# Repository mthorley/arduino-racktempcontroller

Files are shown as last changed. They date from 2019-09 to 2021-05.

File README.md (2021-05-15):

# Arduino Rack Temperature Controller

To temperature control and monitor a small (12U) network rack system using PWM fans and thermometers managed using an Arduino Mega with a custom designed shield:

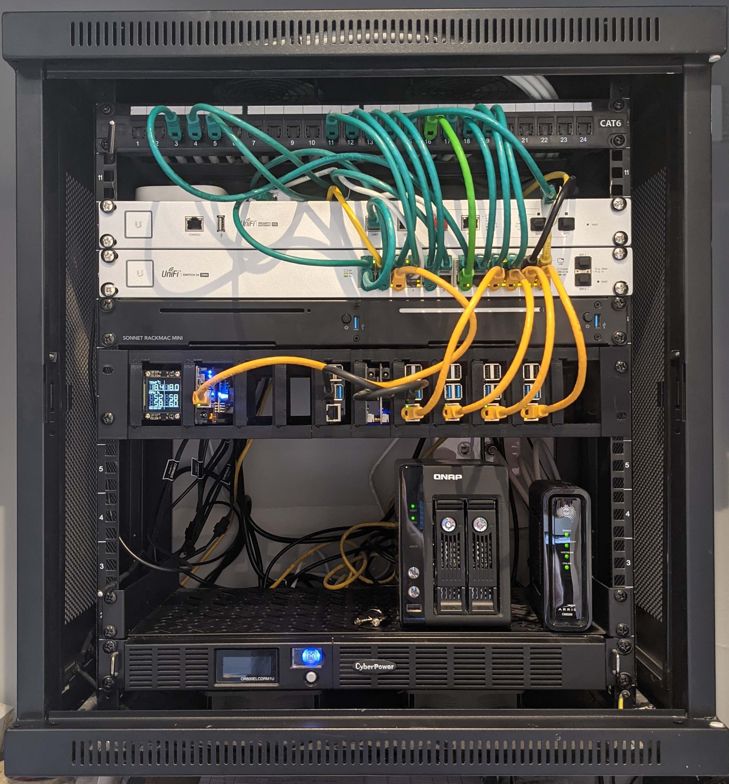
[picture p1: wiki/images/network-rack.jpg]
Image of Network Rack kit


Above rack has:
- 4 fans mounted (2 top and 2 base) in the rack
- 2 temperature sensors one at the top and base
- [Modular 3d printed model](https://github.com/mthorley/2u-rack-3dprint-model) 2U rack housing Arduino temperature controller and OLED shown far left

# Features and Specification
* Uses [Freetronics EtherMega](https://www.freetronics.com.au/collections/arduino/products/ethermega-arduino-mega-2560-compatible-with-onboard-ethernet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) Arduino board although likely any Mega board can reuse the shield
* Shield outline derived from Jonathan Oxer's [ProtoShieldMega](https://github.com/freetronics/ProtoShieldMega)
* Power over Ethernet 802.3af support using [Freetronics PoE module](https://www.freetronics.com.au/products/power-over-ethernet-regulator-8023af) to power the board (and reset it), thermometers, fans and display to simplify power and wire management
* Measures temperatures using [DS18B20](https://makeradvisor.com/tools/ds18b20-digital-temperature-sensor/) housed in metal cable assembly with an accuracy of +/- 0.5&deg;C
* Uses [Freetronics OLED](https://www.freetronics.com.au/pages/oled128-quickstart-guide) via SPI to display the temperature and fan states of the rack
* Works with PWM fans of either 5 or 12V and supports configurable frequency (default 25kHz)
* Uses an [passive infrared sensor](https://www.keyestudio.com/2016-new-keyestudio-pir-motion-sensor-for-arduino-p0488-p0488.html) to prevent burn in for OLED display, only enabling the display on a PIR trigger
* Monitors and displays fan tachometer output to verify RPM is within expected range and fan has not stalled
* Publishes all fan, temperature, error states and logs to an MQTT endpoint and topics for analysis and visualisation
* Software must support any number of temperature devices and fans to enable testing and reuse

# Initial Design
Initial design was based on a separate (non-shield) board using a [MAX31790](https://www.maximintegrated.com/en/products/sensors/MAX31790.html) for fan PWM control and tach measurement integrated with an Arduino Uno using I<sup>2</sup>C. However due to Uno memory limitations of <32k, I upgraded to the Mega with 256k. Code is however included under [MAX31790FanControl.cpp](src/MAX31790FanControl.cpp).

Using a Mega also enabled the PWM control and tach measurement to be done by the Mega pinout and all in software simplifying the overall hardware solution.

# Shield Design
The shield design outline is based on [ProtoShieldMega](https://github.com/freetronics/ProtoShieldMega). The top side of the PCB layout is illustrated. The schematic and PCB design files are under [Eagle](/Eagle). EAGLE PCB design software is available from https://www.autodesk.com/products/eagle/free-download and is free for non-commercial use.

## Pin Mapping
| Pin | Mapping |
|-----|---|
|2, 4, 7| OLED DC, Reset, CS |
|8 | Onewire DS for thermos |
| 11, 12, 5, 3 | Fan PWM 1-4 |
| 18, 19, 20, 21 | Fan Tach 1-4 for RPM interrupts |
| 6 | IR sensor |

## Schematic
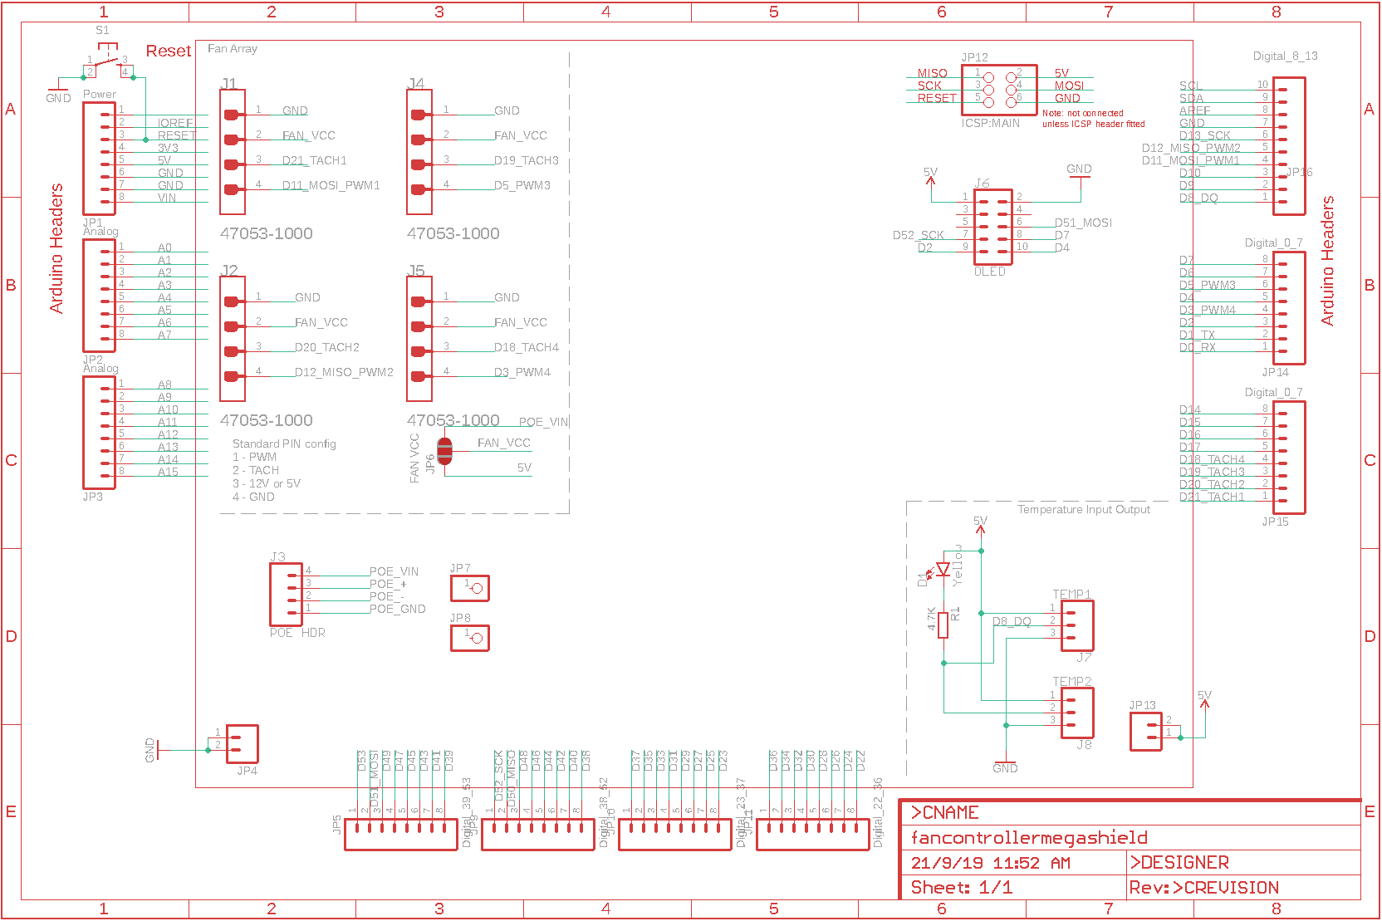
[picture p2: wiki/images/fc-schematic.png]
Shield schematic


## PCB
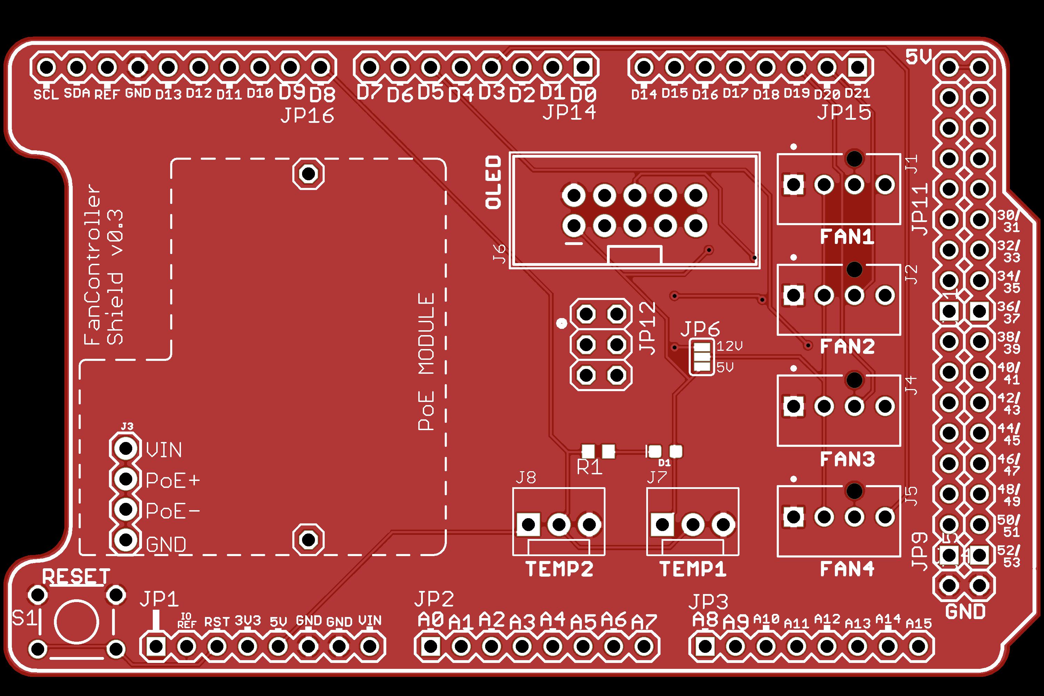
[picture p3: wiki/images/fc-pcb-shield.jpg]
Rack Temp Controller PCB


## Manufacture
I used [DirtyPCBs](https://dirtypcbs.com/store/pcbs) to manufacture the boards. They also support [design rules checking and CAM Gerber export](https://dirtypcbs.com/store/pcbs/about#cam) for EAGLE, which ensures the PCB layout conforms to their manufacture processes and the Gerber files produced will pass.

I then soldered (or used solder paste for surface mount) the parts in place. For the surface mount work, I used a heat gun and roughly followed the [heat profile](http://www.chemtools.com.au/download/technical-and-safety-data-sheets/solders-pastes-and-fluxes/SAC305CR318%20SAC305%20Solder%20Paste/SAC305CR318%20TDS.pdf) by modifying the gun temperature manually. [YouTube videos](https://www.youtube.com/watch?v=W0BhGieg4II) explain how to do this. 

## Shield Mounted
The shield mounted with the EtherMega.

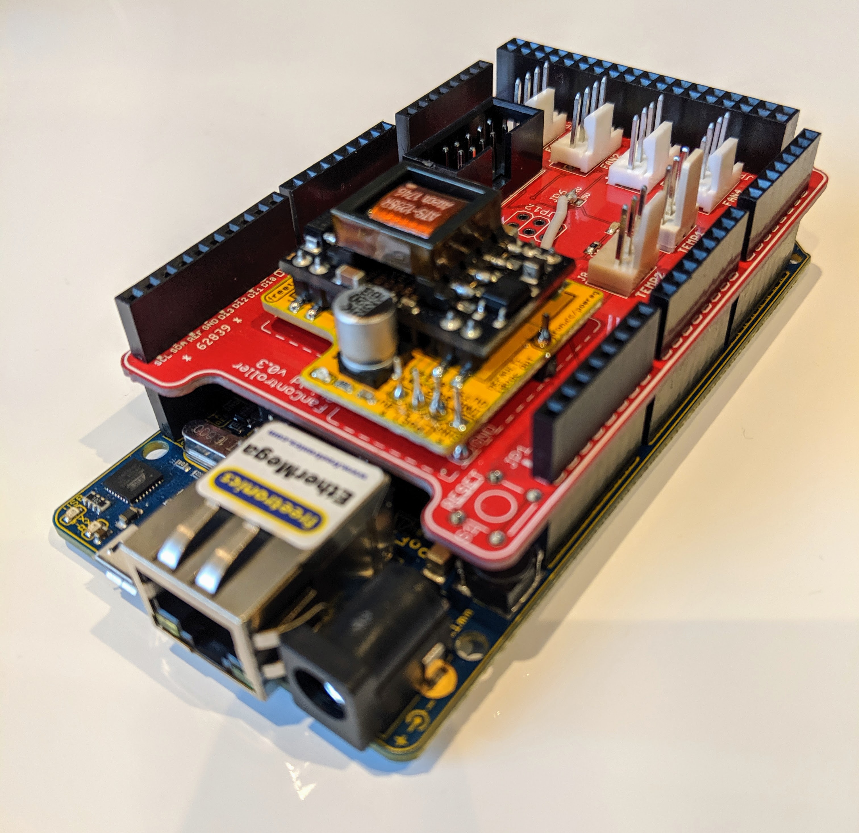
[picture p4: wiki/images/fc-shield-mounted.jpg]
Shield mounted


Minor error on the power circuit which required a track cut and wire from VIN to Fan power. This has been corrected on the Eagle files.

# Display
OLED display to render fan and temperature states showing the fan temperatures in the top row, and the fan RPMs as a percentage of maximum RPM in the lower rows. The fan RPM % does not always accurately map to the input PWM duty cycle - the [fans](https://noctua.at/en/nf-s12b-redux-1200-pwm/specification) I am using have a +/- 10% variance on RPM. The display also supports 90 degree rotation to support rack mounting.

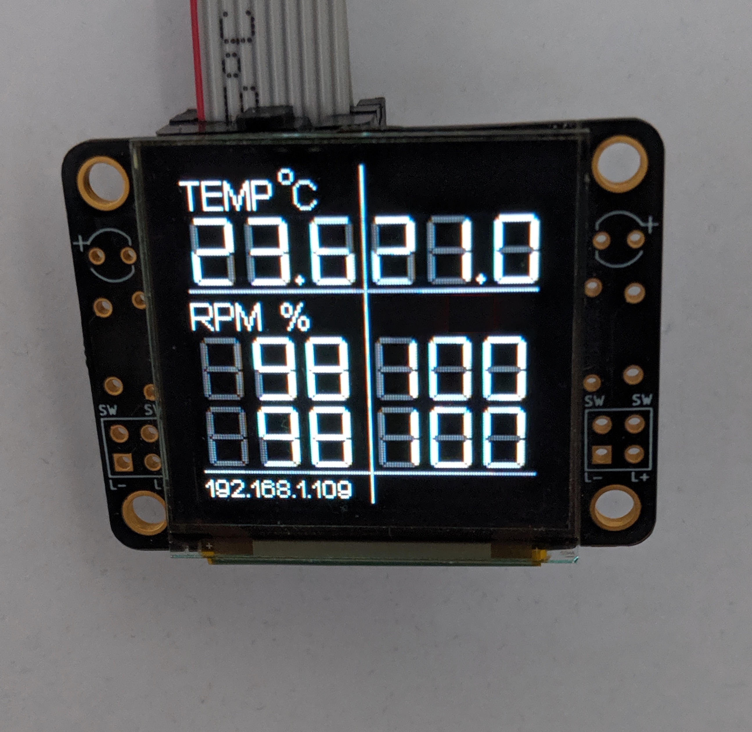
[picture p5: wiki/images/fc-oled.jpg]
OLED display


## Font Generation for OLED
Generated new fonts using [GLDCFontCreator](https://github.com/freetronics/FTOLED/wiki/Displaying-Text#defining-new-fonts).

## MQTT Dashboard
I used the mobile app [IoT MQTT Panel](https://play.google.com/store/apps/details?id=snr.lab.iotmqttpanel.prod&hl=en) to render the MQTT topics which supports configurable panels per topic and different rendering options:

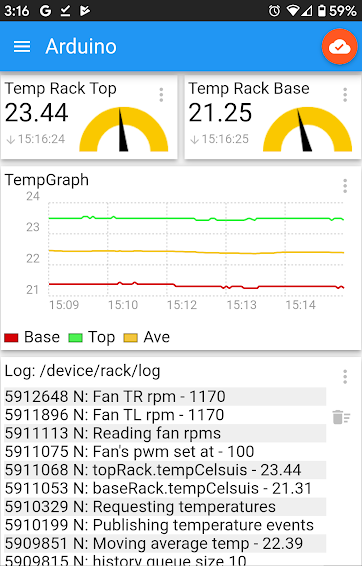
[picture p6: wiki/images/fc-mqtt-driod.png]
MQTT dashboard


# Code 
Development done using [PlatformIO](https://platformio.org/) which supports multiple boards and library management.  

## Explanation
The main routine loop executes the [RackTempController](src/RackTempController.cpp) process method below which reads the temperature sensors, adjusts the fan speed based on the temperatures, reads and verifies the fan speed RPM is as requested by the PWM dutycycle within a tolerance and analyses temperature trends using a moving average.

```c++ 
void RackTempController::process(RackState_t& rs) {
    
    // read temperatures
    readTempStates(rs.thermos);

    // adjust fan speeds based on temps
    adjustFanSpeeds(rs);
    
    // read fan tach/rpms - delay of 750ms per fan
    readFanSpeeds(rs.fans);

    // verify fan PWMs matches RPMs
    verifyFanStates(rs.fans);

    // analyse trends
    analyseTrends(rs);
};
```
Thermos and fan configuration is created via [RackTempController::build()](src/RackTempController.cpp#L219) which enables any number of thermos or fans to be used. The OLED display class however, is fixed to the specification above.

## Dependent Libraries

All libraries were loaded and managed used PlatformIO's library management. 

| Library | Purpose |
|---|---|
| DallasTemperature | Measures temperature of DS18* devices using OneWire |
| FTOLED  | Graphics library to drive OLED |
| SD | Dependency for FTOLED - not used |
| Ethernet | Ethernet, DHCP support |
| ArduinoMqttClient | MQTT client |
| TimerOne | PWM control for Timer1 |
| TimerThree | PWM control for Timer3 |
| ArduinoLog | Logging framework |
| ArduinoSTL | STL library used for map, vector etc |

## Rack Mount

Further details on the rack mount design: [3D printed model](https://github.com/mthorley/2u-rack-3dprint-model).

# TODO
- Update this README!
- Create a config endpoint - possibly via MQTT subscribe to enable changes to MQTT params, temp threshold etc. 
- Improve MQTT events
- Watchdog via AWS lambda which reboots via PoE
- Look at FreeRTOS or [Helios](https://github.com/MannyPeterson/HeliOS) and work out if its worth it
- Make it cheaper

# Credits
First and foremost to [Jonathan Oxer](https://www.patreon.com/superhouse).

Secondly all the excellent library contributors used in the project.

# License
Hardware design licensed under the TAPR Open Hardware License (www.tapr.org/OHL) and GNU. The [license](Eagle/license) folder within this repository also contains a copy of this license in plain text format.

Software licensed under GPLv3 - see [license.md](license.md) file for details.

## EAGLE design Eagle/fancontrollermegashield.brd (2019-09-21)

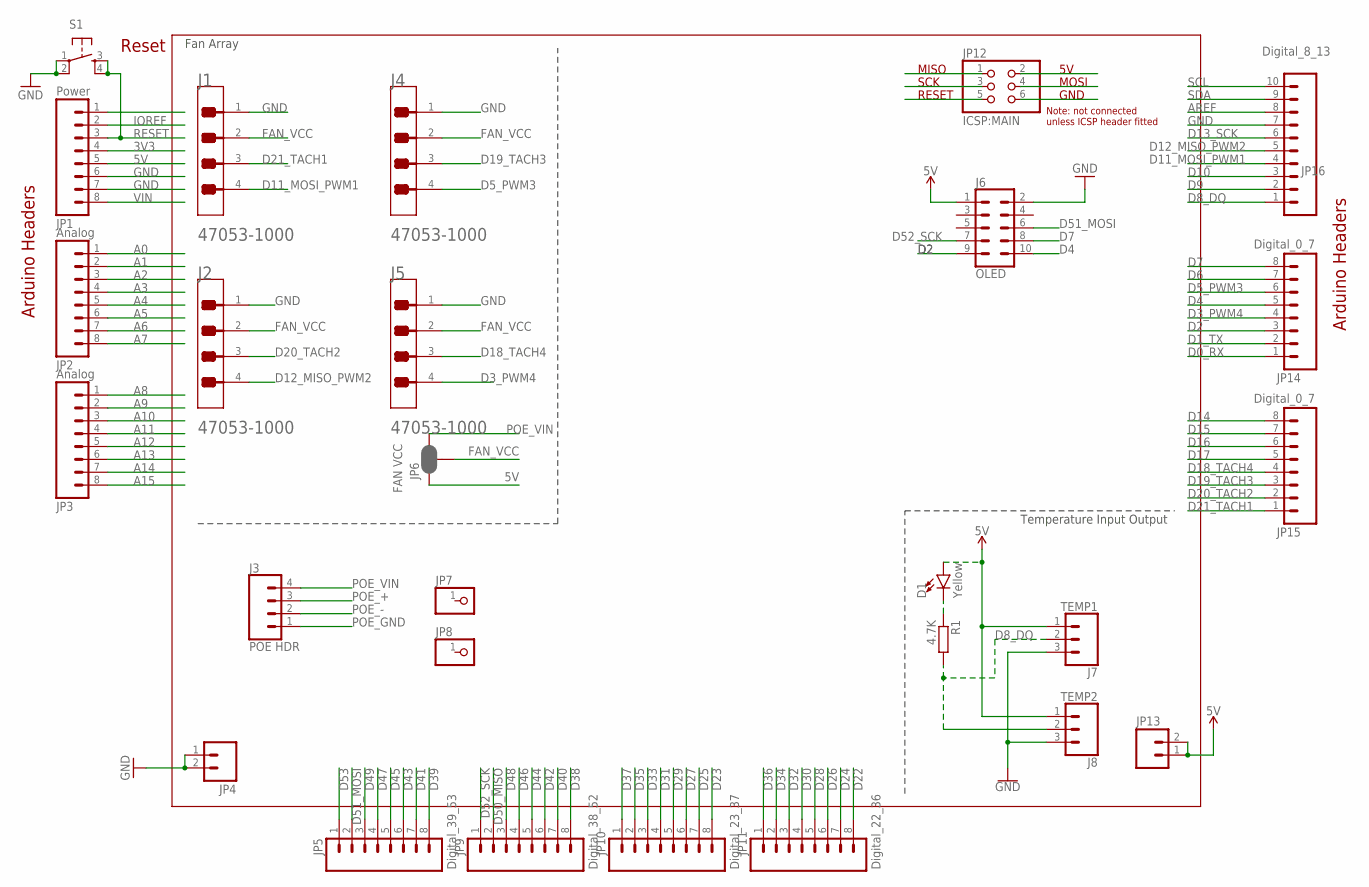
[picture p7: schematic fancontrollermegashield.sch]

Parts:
D1: Yellow; LED-0603
J1: FAN1; MOLEX_47053-1000_0
J2, J4, J5: MOLEX_47053-1000MOLEX_47053-1000_0_0; MOLEX_47053-1000_0
J3: POE HDR; 1X04
J6: OLED; 2X5-SHROUDED
J7: TEMP1; MOLEX-1X3
J8: TEMP2; MOLEX-1X3
JP1: Power; 1X08
JP2, JP3: Analog; 1X08
JP4, JP13: M02PTH; 1X02
JP5: Digital_39_53; 1X08
JP6: FAN VCC; SMT-JUMPER_3_2-NC_PASTE_SILK
JP7, JP8: PINHD-1X1; 1X01
JP9: Digital_38_52; 1X08
JP10: Digital_23_37; 1X08
JP11: Digital_22_36; 1X08
JP12: ICSP:MAIN; 2X03
JP14, JP15: Digital_0_7; 1X08
JP16: Digital_8_13; 1X10
R1: 4.7K; R0603
S1: TAC_SWITCHPTH; TACTILE-PTH

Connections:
3V3: JP1.4
5V: D1.A, J6.1, J7.1, J8.1, JP1.5, JP6.1, JP13.1, JP13.2
A0: JP2.1
A1: JP2.2
A2: JP2.3
A3: JP2.4
A4: JP2.5
A5: JP2.6
A6: JP2.7
A7: JP2.8
A8: JP3.1
A9: JP3.2
A10: JP3.3
A11: JP3.4
A12: JP3.5
A13: JP3.6
A14: JP3.7
A15: JP3.8
AREF: JP16.8
D0_RX: JP14.1
D1_TX: JP14.2
D2: J6.9, JP14.3
D3_PWM4: J5.4, JP14.4
D4: J6.10, JP14.5
D5_PWM3: J4.4, JP14.6
D6: JP14.7
D7: J6.8, JP14.8
D8_DQ: J7.2, J8.2, JP16.1, R1.2
D9: JP16.2
D10: JP16.3
D11_MOSI_PWM1: J1.4, JP16.4
D12_MISO_PWM2: J2.4, JP16.5
D13_SCK: JP16.6
D14: JP15.8
D15: JP15.7
D16: JP15.6
D17: JP15.5
D18_TACH4: J5.3, JP15.4
D19_TACH3: J4.3, JP15.3
D20_TACH2: J2.3, JP15.2
D21_TACH1: J1.3, JP15.1
D22: JP11.8
D23: JP10.8
D24: JP11.7
D25: JP10.7
D26: JP11.6
D27: JP10.6
D28: JP11.5
D29: JP10.5
D30: JP11.4
D31: JP10.4
D32: JP11.3
D33: JP10.3
D34: JP11.2
D35: JP10.2
D36: JP11.1
D37: JP10.1
D38: JP9.8
D39: JP5.8
D40: JP9.7
D41: JP5.7
D42: JP9.6
D43: JP5.6
D44: JP9.5
D45: JP5.5
D46: JP9.4
D47: JP5.4
D48: JP9.3
D49: JP5.3
D50_MISO: JP9.2
D51_MOSI: J6.6, JP5.2
D52_SCK: J6.7, JP9.1
D53: JP5.1
FAN_VCC: J1.2, J2.2, J4.2, J5.2, JP6.2
GND: J1.1, J2.1, J4.1, J5.1, J6.2, J7.3, J8.3, JP1.6, JP1.7, JP4.1, JP4.2, JP16.7, S1.1, S1.2
IOREF: JP1.2
unnamed: D1.C, R1.1
POE_+: J3.3
POE_-: J3.2
POE_GND: J3.1
POE_VIN: J3.4, JP6.3
RESET: JP1.3, S1.3, S1.4
SCL: JP16.10
SDA: JP16.9
VIN: JP1.8

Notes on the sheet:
Arduino Headers
Reset
GND
MISO
RESET
SCK
MOSI
Note: not connected unless ICSP header fitted
Temperature Input Output
Fan Array

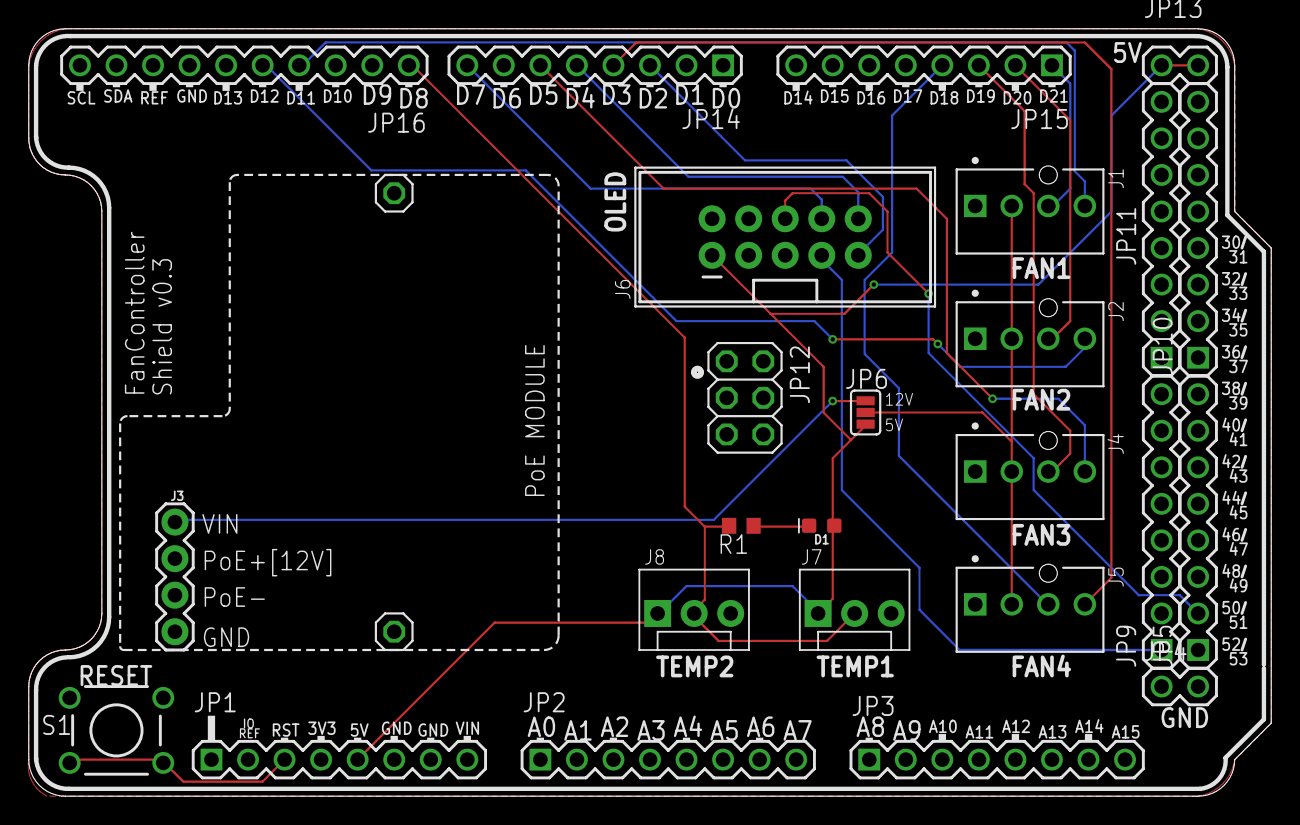
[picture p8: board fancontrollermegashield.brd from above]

Board: 2 copper layers, 86.4 x 53.3 mm, 27 parts (0 on the bottom side), 20 nets.

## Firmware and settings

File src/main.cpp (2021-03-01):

#ifndef UNIT_TEST

#include <ArduinoLog.h>
#include "RackTempController.h"
#include "OLEDDisplay.h"
#include "MqttManager.h"
//#include "MAX31790FanControl.h"
#include "ArduinoFanControl.h"

void onMqttMessage(int messageSize);

/*
All pin usage
2, 4, 7         - OLED
8               - Onewire DS
11, 12, 5, 3    - Fan PWM
18, 19, 20, 21  - Fan Tach for RPM
6               - IR sensor
*/

// Pins
#define PIN_DC     2        // OLED
#define PIN_RESET  4        // OLED
#define PIN_CS     7        // OLED
#define PIN_ONE_WIRE_BUS 8  // Onewire for DS18B20s
#define PIN_IR     6        // IR Sensor

byte mac[] = {
    0xDE, 0xAD, 0xBE, 0xEF, 0xFE, 0xED
};

// MQTT config
const char* CLIENT_ID      = "RackTempController.Arduino.Client";
const char* MQTT_SERVER_IP = "k8smqtt"; //"192.168.2.11";
const uint16_t MQTT_PORT   = 1883;

// Setup a oneWire instance to communicate with any OneWire device
OneWire oneWire(PIN_ONE_WIRE_BUS);

//MAX31790           fanControl(0xC0, 4);
ArduinoFanControl  fanControl(4);
RackTempController rtc(oneWire, fanControl);
//OLEDDisplay        oled(PIN_CS, PIN_DC, PIN_RESET, PIN_IR);
OLEDDisplay        oled(PIN_CS, PIN_DC, PIN_RESET);
EthernetClient     ethClient;
MqttClient         mqttClient(ethClient);
MqttManager        mqttManager(&mqttClient, CLIENT_ID, MQTT_SERVER_IP, MQTT_PORT);

bool ethernetPresent = false;
bool displayOnNotOff = true;

RESULT ethernetSetup() {
    RESULT res = RES_OK;

    if (Ethernet.linkStatus() == LinkOFF) {
        Log.error(F("Ethernet cable is not connected."));
        res = ERR_NO_CABLE_DETECTED;
        return res;
    }

    // Start the Ethernet connection and the server
    if (Ethernet.begin(mac)==0) {
        Log.error(F("Failed to get IP from DHCP"));
        res = ERR_FAILED_TO_GET_IP_FROM_DHCP;
        return res;
    }

    // Check for Ethernet hardware present
    if (Ethernet.hardwareStatus() == EthernetNoHardware) {
        Log.error(F("Ethernet hardware not found"));
        res = ERR_NO_ETHERNET_HW;
        return res;
    }

    ethernetPresent = true;    
    return res;
}

// log support
void printTimestamp(Print* logOutput) {
    char c[12];
    sprintf(c, "%10lu ", millis());
    logOutput->print(c);
}

void printNewline(Print* logOutput) {
    logOutput->print('\n');
}

void setup(void)
{
    Serial.begin(9600);

    // setup logging
    Log.begin(LOG_LEVEL_WARNING, &mqttManager); // use &Serial only to avoid MQTT events
//    Log.begin(LOG_LEVEL_VERBOSE, &mqttManager);   // use &Serial only to avoid log output being published as events
    Log.setPrefix(printTimestamp);
    Log.setSuffix(printNewline);

    fanControl.initialise();

    oled.initialise();

    RESULT res = ethernetSetup();
    if (res == RES_OK) {
        oled.render("Ethernet initialised");
        Log.notice(F("Ethernet initialised"));
        
        if (mqttManager.initialise()==0) {
            oled.render("Mqtt initialised");
            Log.notice(F("Mqtt initialised"));
        }
        else {
            oled.render("Mqtt failed initialise");
            Log.notice(F("Mqtt failed to initialise"));
        } 
    }
    else {
        oled.render("Ethernet failed to initialised");
        Log.error(F("Ethernet failed to initalise %d"), res);
    }
}
  
void loop(void) {

    NetworkState_t ns;
    RackState_t rs = rtc.build();
    
    if (ethernetPresent) {
        ns.ethernetIP = Ethernet.localIP();
        ns.mqttServerIP = MQTT_SERVER_IP;
        ns.mqttPort = MQTT_PORT;

        mqttManager.poll();
    }

    // read temperatures, modify fan speed
    rtc.process(rs);

    // render rack state, network state
    if (displayOnNotOff)
        oled.render(rs, ns);

    if (ethernetPresent) {
        // emit rackstate data, will reconnect if required
        mqttManager.publish(rs);

        // maintain IP via DHCP
        int res = Ethernet.maintain();
        if (res!=0)
            Log.notice(F("Ethernet maintain - %d"), res);
    }    
}

void onMqttMessage(int messageSize) {
    
    Serial.println("rx");
    char buf[128];
    int i=0;
    while(mqttClient.available()) {
        if (i<128) 
            buf[i++] = mqttClient.read();
    }
    
    Serial.println(buf);

    if (buf[0]=='1') {
        oled.displayOn();
        displayOnNotOff = true;
    }
    else if(buf[0]=='0') {
        oled.displayOff();
        displayOnNotOff = false;
    }
}

#endif

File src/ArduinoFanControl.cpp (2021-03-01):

#include "ArduinoFanControl.h"

// interrupt callbacks
extern void ArduinoFanControl_tach1Count();
extern void ArduinoFanControl_tach2Count();
extern void ArduinoFanControl_tach3Count();
extern void ArduinoFanControl_tach4Count();

volatile uint16_t ArduinoFanControl_tach1 = 0;
volatile uint16_t ArduinoFanControl_tach2 = 0;
volatile uint16_t ArduinoFanControl_tach3 = 0;
volatile uint16_t ArduinoFanControl_tach4 = 0;

// externs
void ArduinoFanControl_tach1Count()
{
    ArduinoFanControl_tach1++;
}

void ArduinoFanControl_tach2Count()
{
    ArduinoFanControl_tach2++;
}

void ArduinoFanControl_tach3Count()
{
    ArduinoFanControl_tach3++;
}

void ArduinoFanControl_tach4Count()
{
    ArduinoFanControl_tach4++;
}

ArduinoFanControl::ArduinoFanControl(const uint8_t fans) : 
    FanControl(fans), 
    _pwmPeriod(40) {}  // 40us == 25kHz

/**
 * Initialise as PWM timers, tach inputs and
 * attach interrupts to measure.
 */
RESULT ArduinoFanControl::initialise()
{
    // Use two timers to drive 4 PWM pins - 2 each
    Timer1.initialize(_pwmPeriod);
    Timer3.initialize(_pwmPeriod);

    // For reading TACHs
    // Pullup - since TACH output is open collector and pullup rc reduces noise.
    pinMode(PIN_TACH1, INPUT_PULLUP);
    pinMode(PIN_TACH2, INPUT_PULLUP);
    pinMode(PIN_TACH3, INPUT_PULLUP);
    pinMode(PIN_TACH4, INPUT_PULLUP);

    // See https://www.arduino.cc/reference/en/language/functions/external-interrupts/attachinterrupt/
    attachInterrupt(digitalPinToInterrupt(PIN_TACH1), ArduinoFanControl_tach1Count, CHANGE);
    attachInterrupt(digitalPinToInterrupt(PIN_TACH2), ArduinoFanControl_tach2Count, CHANGE); 
    attachInterrupt(digitalPinToInterrupt(PIN_TACH3), ArduinoFanControl_tach3Count, CHANGE); 
    attachInterrupt(digitalPinToInterrupt(PIN_TACH4), ArduinoFanControl_tach4Count, CHANGE); 
    
    ArduinoFanControl_tach1 = 0;
    ArduinoFanControl_tach2 = 0;
    ArduinoFanControl_tach3 = 0;
    ArduinoFanControl_tach4 = 0;

    return RES_OK;
}

/**
 * Set PWM for fanid.
 * dutyCycle is ranged 0 to 100
 */
RESULT ArduinoFanControl::setPWM(const uint8_t fanid, const uint16_t dutyCycle)
{
    ASSERT_RANGE_DUTY_CYCLE(dutyCycle);
    ASSERT_RANGE_FAN_ID(fanid, getFanCount());

    // duty is from 0 to 1023
    switch (fanid)
    {
    case 1:
        Timer1.pwm(PIN_FAN1_T1, ((float)dutyCycle / 100) * 1023);
        break;

    case 2:
        Timer1.pwm(PIN_FAN2_T1, ((float)dutyCycle / 100) * 1023);
        break;

    case 3:
        Timer3.pwm(PIN_FAN3_T3, ((float)dutyCycle / 100) * 1023);
        break;

    case 4:
        Timer3.pwm(PIN_FAN4_T3, ((float)dutyCycle / 100) * 1023);
        break;

    default:
        break;
    }

    return RES_OK;
}

/**
 * Set PWM for all fans to duty
 */
RESULT ArduinoFanControl::setPWMForAll(const uint16_t dutyCycle)
{
    ASSERT_RANGE_DUTY_CYCLE(dutyCycle);
    
    RESULT res = RES_OK;
    for(int i=1; i<=getFanCount(); i++) {
        res = res & setPWM(i, dutyCycle);
    }
    return res;
}

RESULT ArduinoFanControl::getTachHz(const uint8_t fanid, uint16_t& tachHz) 
{
    ASSERT_RANGE_FAN_ID(fanid, getFanCount());
    
    unsigned long tachTime = 750; //ms
    measureTach(fanid, tachTime);
    float tHz = readTach(fanid, tachTime);
    tachHz = round(tHz);
    return RES_OK;
}

RESULT ArduinoFanControl::getRPM(const uint8_t fanid, uint16_t& rpm) 
{
    uint16_t tachHz;
    getTachHz(fanid, tachHz);
    // Div 2 since TACH returns 2 pulses per revolution:
    // https://noctua.at/media/wysiwyg/Noctua_PWM_specifications_white_paper.pdf 
    rpm = (tachHz * 60.0) / 2;
    return RES_OK;
}

// private

void ArduinoFanControl::measureTach(const uint8_t fanid, unsigned long msWait)
{
    // reset interrupt count
    switch (fanid) {
        case 1:
            ArduinoFanControl_tach1 = 0;
            break;
        case 2:
            ArduinoFanControl_tach2 = 0;
            break;
        case 3:
            ArduinoFanControl_tach3 = 0;
            break;
        case 4:
            ArduinoFanControl_tach4 = 0;
            break;
    }

    // force wait to accumulate interrupts
    unsigned long t1 = millis();
    do {
        // nop
    } while ((millis() - t1) < msWait);
}

float ArduinoFanControl::readTach(const uint8_t fanid, unsigned long ms)
{
    // See https://www.pjrc.com/teensy/td_libs_TimerOne.html Interrupt Context Issues
    // noInterrupts();

    uint16_t tach = 0;
    switch (fanid) {
        case 1:
            tach = ArduinoFanControl_tach1;
            break;
        case 2:
            tach = ArduinoFanControl_tach2;
            break;
        case 3:
            tach = ArduinoFanControl_tach3;
            break;
        case 4:
            tach = ArduinoFanControl_tach4;
            break;
    }
    // interrupts();
    
    // Divide by 2: since interrupt is CHANGE: H-L and L-H for accuracy.
    float tachHz = (tach * 1000.0 ) / (2 * ms);
    return tachHz;
}

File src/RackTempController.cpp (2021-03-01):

#include "RackTempController.h"
#include <ArduinoLog.h>

/**
 * Process temperatures, modify fan speed, check for errors, update trends
 */
void RackTempController::process(RackState_t& rs) {
    
    // read temperatures
    readTempStates(rs.thermos);

    // adjust fan speeds based on temps
    adjustFanSpeeds(rs);
    
    // read fan tach/rpms - delay of 750ms per fan
    readFanSpeeds(rs.fans);

    // verify fan PWMs matches RPMs
    verifyFanStates(rs.fans);

    // analyse trends
    analyseTrends(rs);
};

void RackTempController::analyseTrends(RackState_t& rs) /* const */ {

    // cache RackState for trend analysis
    cache(rs);
    
    float acc = 0.0;
    uint16_t samples = 0;

    // iterate through history to accumulate temps, count samples
    for(auto it = _rsHistory.begin(); it != _rsHistory.end(); it++) {
        for(auto tt = it->thermos.begin(); tt != it->thermos.end(); tt++) {
            acc += tt->second.tempCelsuis;
            samples++;
        }
    }
    float movingAve = (float)acc/samples;
    Log.notice(F("Moving average temp - %F"), movingAve);

    rs.aveTempCelsius = movingAve;
    //rs.trend.movingAveTempCelsuis = movingAve;
    //rs.trend.accFanError =   
}

/**
 * Maintains FIFO queue. Not using queue STL 
 * as it doesn't provide iterator.
 */
void RackTempController::cache(const RackState_t& rs) {

    _rsHistory.push_back(rs);
    if (_rsHistory.size() > _historyDepth) {
        _rsHistory.pop_front();
    }
    Log.notice(F("history queue size %d"), _rsHistory.size());
}

/**
 * Confirm for the fan, that 
 * - RPMs are above minimum (if minRpm is not zero), i.e. the fan is detected as spinning
 * - PWM setting and RPM reading is within expectation, i.e. +/- 10%
 */
RESULT RackTempController::checkRpm(FanState_t& fs) const {

    // is fan spinning at all?
    if (fs.minRpm > 0 && fs.rpm < fs.minRpm) {
        fs.result = ERR_FAN_NOT_OPERATIONAL;
        Log.error(F("Fan %s is not operational"), fs.position.c_str());
        return ERR_FAN_NOT_OPERATIONAL;
    }

    // is the fan within expected RPM variance given dutyCycle?
    uint16_t expectedRpm = round( fs.maxRpm * (float)fs.pwm/100 );
   
    int16_t r = round(expectedRpm - fs.maxRpm * _rpmVariance);
    uint16_t minExpectedRpm = (r<0) ? 0 : r;
    uint16_t maxExpectedRpm = round(expectedRpm + fs.maxRpm * _rpmVariance);

    // if rpm is out of range of expectated rpm
    if (fs.rpm < minExpectedRpm || fs.rpm > maxExpectedRpm)
    {
        /* if (fs.rpm > fs.maxRpm) {
            // assume this is NOT an error condition - perhaps tach noise or manufacture issue?
            Log.warning(F("Fan %s is spinning at %d rpm, which is faster than maxRpm: %d"), 
                fs.position.c_str(),
                fs.rpm,
                fs.maxRpm);
        }
        else */ 
        {
            // we are out of range
            fs.result = ERR_FAN_TACH;
            Log.error(F("Rpm of fan %s is out of range: %d is not between %d to %d"), 
                fs.position.c_str(),
                fs.rpm,
                minExpectedRpm,
                maxExpectedRpm);
            return ERR_FAN_TACH;
        }
    }

    return RES_OK;
}

/**
 * Verify fan state: speed
 */
void RackTempController::verifyFanStates(Fans_t& fans) const {
    for (auto it = fans.begin(); it != fans.end(); it++) {
        checkRpm(it->second);
    }
}

void RackTempController::adjustFanSpeeds(RackState_t& rs) {

    // Basic rule: any thermo above threshold temp, set it to full spin
    // else run it at half speed.
    uint8_t dutyCycle = 50;
    for (auto it = rs.thermos.begin(); it != rs.thermos.end(); it++) {
        Temperature_t& thermo = it->second;
        if (thermo.tempCelsuis > _TEMP_THRESHOLD) {
            dutyCycle = 100;
        }
    }

    // update fan speed and state
    _fanControl.setPWMForAll(dutyCycle);
    for (auto it = rs.fans.begin(); it != rs.fans.end(); it++) {
        it->second.pwm = dutyCycle;
    }

    Log.notice(F("Fan's pwm set at - %d"), dutyCycle);
}

/**
 * Get tach/rpm for all fans
 * Delay of 750ms per fan within getRPM()
 */
void RackTempController::readFanSpeeds(Fans_t& fans) {
    
    uint16_t rpm = 0;
    
    Log.notice(F("Reading fan rpms"));

    for (auto it = fans.begin(); it != fans.end(); it++) {
        _fanControl.getRPM(it->first, rpm);
        it->second.rpm = rpm;
        Log.notice(F("Fan %s rpm - %d"), it->second.position.c_str(), rpm);
    }
};

void RackTempController::readTempStates(Thermos_t& thermos) {

    // Initialise sensors each read incase new sensors are added/removed.
    _tempSensors.begin();

    // useful for new thermo's to get deviceAddress
    //  searchAndPrintAddresses();
    
    // Iterate through all devices ensuring they are still connected
    for (auto it = thermos.begin(); it != thermos.end(); it++) {
        Temperature_t& thermo = it->second;
        if (!_tempSensors.isConnected(thermo.addr)) {
            Log.warning(F("Unable to find thermometer %s"), it->first.c_str());
            thermo.result = ERR_FAILED_TO_FIND_DEVICE;
        }
    }
    
    // Send command to all DS18* for temperature conversion
    Log.notice(F("Requesting temperatures"));
    _tempSensors.requestTemperatures();

    // Get temperature for each thermometer
    for (auto it = thermos.begin(); it != thermos.end(); it++) {
        Temperature_t& thermo = it->second;
        // if device found, then read temp
        if (thermo.result != ERR_FAILED_TO_FIND_DEVICE) {
            if ((thermo.tempCelsuis = _tempSensors.getTempC(thermo.addr)) == DEVICE_DISCONNECTED_C) {
                thermo.result = ERR_FAILED_TO_READ_TEMP;
                Log.warning(F("Failed to read %s temperature"), it->first.c_str());
            }
            else {
                Log.notice(F("%s.tempCelsuis - %F"), it->first.c_str(), thermo.tempCelsuis);
            }
        }
    }
}

/**
 * Search for all devices and printout addresses
 */
void RackTempController::searchAndPrintAddresses() {

    DeviceAddress deviceAddr;
    // locate devices on the bus
    Serial.println("Locating devices...");
    Serial.print("Found ");
    int deviceCount = _tempSensors.getDeviceCount();
    Serial.print(deviceCount, DEC);
    Serial.println(" devices.");
    Serial.println("");

    Serial.println("Printing addresses...");
    for (int i = 0;  i < deviceCount;  i++)
    {
        Serial.print("Sensor ");
        Serial.print(i+1);
        Serial.print(" : ");
        _tempSensors.getAddress(deviceAddr, i);
        printAddress(deviceAddr);
    }
}

// function to print a device address for DS18*
void RackTempController::printAddress(const DeviceAddress deviceAddress) const
{
    for (uint8_t i = 0; i < 8; i++)
    {
        Serial.print("0x");
        if (deviceAddress[i] < 0x10) 
            Serial.print("0");
        Serial.print(deviceAddress[i], HEX);
        if (i < 7) 
            Serial.print(", ");
    }
    Serial.println("");
}
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

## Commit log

2019-09-21 Eagle files
    [fancontrollermegashield.brd, fancontrollermegashield.sch]
2019-09-21 Minor corrections
    [fancontrollermegashield.brd, fancontrollermegashield.sch]
2019-09-26 Fix up fan tach error
    [OLEDDisplay.cpp, RackTempController.cpp]
2019-09-28 Fixed RPM variance issue
    [RackTempController.cpp]
2020-01-27 Added temp threshold to trigger 100% PWM
2020-08-10 Support 90 rotation for rack mount
2020-08-16 Enabled MQTT subscribe callback to switch OLED on/off
2021-01-31 Control of display via device/config topic callback

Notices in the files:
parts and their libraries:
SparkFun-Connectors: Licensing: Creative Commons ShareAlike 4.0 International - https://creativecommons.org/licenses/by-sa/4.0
